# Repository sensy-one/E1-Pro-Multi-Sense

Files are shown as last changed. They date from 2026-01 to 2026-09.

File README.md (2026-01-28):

## 🚀 Sensy-One E1 Pro Multi Sense

The all-in-one open-source sensor designed for Home Assistant, refined through real-world user feedback.

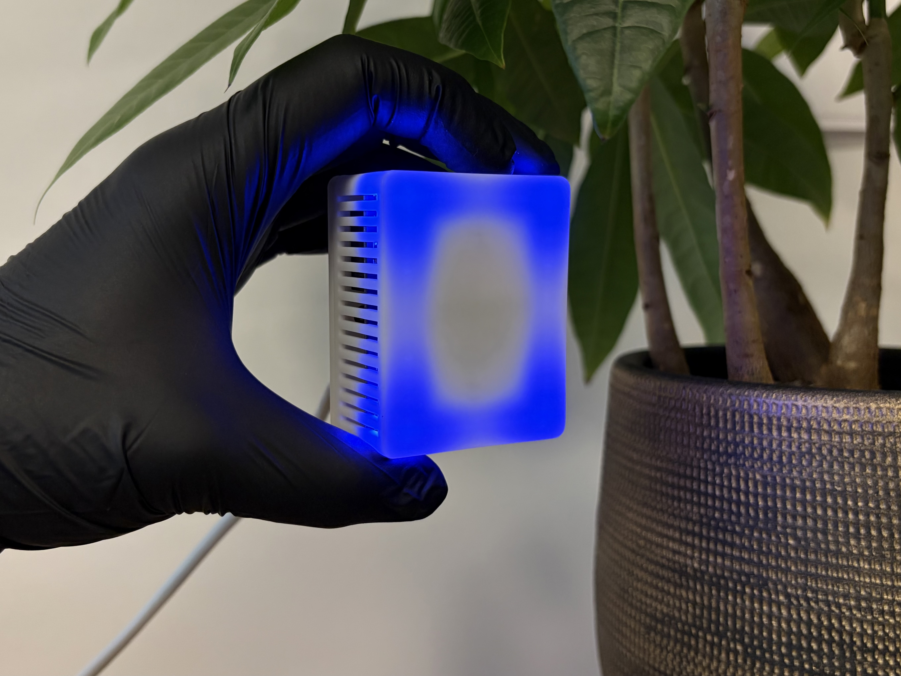
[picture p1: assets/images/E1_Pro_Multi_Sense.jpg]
Sensy-One Banner


The Sensy-One E1 Pro Multi Sense is an open-source presence and environmental sensor, built from the ground up with Home Assistant in mind. After extensive prototyping, firmware tuning, and valuable input from users and smart home enthusiasts, the E1 Pro brings together reliable presence detection, real-time air quality monitoring, and ambient light sensing — all in one compact, Home Assistant-ready device!

## ✨ Standout Specs

**Seamless Home Assistant integration**

The E1 Pro is automatically discovered by Home Assistant when running in PoE (Ethernet) mode.

If you choose the Wi-Fi firmware, the device will be automatically discovered via BLE Improv.  
If BLE discovery is not available or fails, the E1 Pro will start its own wireless access point to complete the setup and connect the sensor to Home Assistant — no additional tools required.

**Powered by ESP32-C3**

At its core, the E1 Pro uses the ESP32-C3 module — offering reliable Wi-Fi, Bluetooth Low Energy, and Ethernet support, low power consumption, and full compatibility with ESPHome and Home Assistant integrations.

**Modular mounting options**

The E1 Pro supports modular built-in mounting options for flexible installation, including flush in-wall and in-ceiling add-ons for a clean, integrated finish.

> Note: These built-in mounting options are currently in development and will be released soon, including STEP and STL files for DIY 3D printing, with the option to purchase the mounting add-ons if you don’t have access to a 3D printer.

**Precision-engineered enclosure**

The custom enclosure is optimized for reliable sensing and long-term operation, featuring minimal mmWave signal interference, optimized airflow across sensors, and a passive cooling design. The resin-printed enclosure ensures a clean, high-quality finish and measures 65 × 52 × 30 mm.

**Advanced mmWave presence sensing**

Built around the Hi-Link LD2460 mmWave presence radar module, the E1 Pro continuously tracks presence in real space, including position, distance, and movement. The system supports tracking of up to five targets simultaneously with fast, stable updates at approximately 30 ms.

Dedicated wall and ceiling detection modes ensure accurate sensing for different mounting positions. With support for three configurable detection zones and one exclusion zone, you can precisely control where presence should trigger automations and where it should be ignored.

The radar supports multiple operating modes:
- Side mode with a detection range of up to 6 m, a 120° horizontal field of view, and a 35° vertical pitch angle
- Top-down mode with full 360° coverage and up to an 8 m diameter

Adjustable sensitivity levels (High, Medium, Low) allow fine-tuning for different environments, delivering reliable and responsive presence detection.

**BLE presence & proximity**

The E1 Pro includes a built-in BLE Proxy for Bluetooth-based presence and proximity detection. The BLE Proxy can be enabled or disabled as needed, allowing seamless integration with Home Assistant and other BLE-based tracking solutions for accurate room-level detection of smartphones, wearables, and tags.

**Full-color status LEDs**

The E1 Pro features four front-facing full-color RGB LEDs, providing clear visual feedback for status indication, presence detection, alerts, and ambient lighting effects.

**Built-in buzzer**

The integrated MLT-8530 buzzer delivers clear audio alerts at 80–90 dB and 2.7 kHz, perfect for notifications, warnings, or presence feedback.

**Comprehensive environmental monitoring**

The E1 Pro is equipped with the Bosch BME280 sensor, providing air pressure measurements for environmental monitoring and system integration.

> Note: Temperature and humidity readings from the BME280 are disabled due to self-heating effects inside the enclosure. Air pressure data is used to support the optional SCD40 add-on, which provides accurate CO₂, temperature, and humidity measurements without self-heating impact.

**High-precision CO₂ sensing (add-on)**

For highly accurate air quality measurements, the E1 Pro supports an optional Sensirion SCD40 add-on module. This add-on provides precise CO₂, temperature, and humidity readings and connects directly to the main PCB via a Molex mezzanine connector — no soldering required.

> Note: An optional Bosch BME688 air quality add-on for the E1 Pro is currently in development and will be released soon. This add-on will enable monitoring of eCO₂, VOCs, IAQ, and gas resistance, providing broader air quality insight similar to the S1 Pro.

**Ambient light and UV sensing**

The integrated Lite-On LTR-390UV sensor measures both illuminance (Lux) and UV index (UVI), enabling smart lighting control and sun exposure awareness based on real-time ambient conditions.

## ⚡ From Power On to Home Assistant

The E1 Pro supports Power over Ethernet (PoE) and is automatically discovered by Home Assistant when connected via Ethernet.

If PoE is not available, the device can be powered using 5V USB-C in combination with an RJ45 Ethernet connection.

When using Wi-Fi mode, the E1 Pro can be powered via USB-C or PoE.  
Wi-Fi setup is handled using Bluetooth (Improv) or the built-in access point.

If your Home Assistant setup supports Bluetooth (Improv):
- The E1 Pro will be automatically discovered under Devices & Services.
- Click Add, enter your Wi-Fi credentials, and you're done.

If Bluetooth is not available:
- The E1 Pro will start a Wi-Fi access point named I am Sensy!.
- Connect to it and open http://192.168.4.1 in your browser.
- Enter your Wi-Fi details, click Save, and it will connect to your network.
- The device will then appear in Home Assistant as a discovered device.

## 📍 Best Placement Practices

**Recommended mounting height**

Wall mounting mode:
- 1.6 to 2.6 meters from the floor

Top-down (ceiling) mounting mode:
- 2.0 to 3.0 meters from the floor

**Placement tips:**
- Ensure a clear line of sight to the monitored area — walls, plants, or furniture can reduce detection accuracy.
- Avoid placing near large metal objects (such as fridges, pipes, or servers), as they can reflect mmWave signals.
- Avoid direct airflow from HVAC vents or fans to maintain stable environmental readings.
- Mount away from heat sources to prevent temperature distortion.

## 🧪 CO₂ Calibration (SCD40 add-on)

For faster or more precise calibration, you can use the Forced Calibration button in Home Assistant.

**To calibrate CO₂ manually:**
- Place the sensor in fresh outdoor air.
- In Home Assistant, click Forced Calibration on the E1 Pro.
- The sensor will set a new baseline of 426 ppm (current global outdoor CO₂ level).

**Temperature offset:**
The SCD40 temperature offset is factory-calibrated based on the enclosure design to compensate for internal heat. This offset can also be manually adjusted in Home Assistant if needed to fine-tune temperature accuracy for your environment.

## 🎯 Get in the Zone

The E1 Pro supports up to 3 detection zones and 1 exclusion zone — all configurable as custom polygons with up to 8 points each.  
Instead of adjusting multiple number entities, zones can be configured visually using the Zone Editor tool.

The Zone Editor is available as an official Home Assistant add-on or Docker image and can be found [here](https://github.com/sensy-one/home-assistant-addons).

## 📶 Flashing Wi-Fi Firmware

To switch the E1 to Wi-Fi mode, you need to flash the Wi-Fi factory firmware manually.

**Flash Wi-Fi factory firmware**
- Download the latest Wi-Fi factory firmware from the [releases page](https://github.com/sensy-one/E1-Pro-Multi-Sense/releases).
- Connect the E1 to your computer using a USB-C cable.
- Open the ESPHome web flasher: https://web.esphome.io/
- Click Connect and select the correct COM port.
- Choose Install and select the Wi-Fi factory firmware file you downloaded.
- Once flashing is complete, disconnect and power the E1 using USB-C or PoE.
- The E1 will start Wi-Fi provisioning using Bluetooth (Improv) or its built-in access point.

## 🔄 Firmware on the Fly

Keep your E1 up to date with regular OTA updates.  
We continuously improve performance and add new features to keep your device reliable and future-ready.

**Install OTA Updates**
- Download the latest OTA firmware from the [releases page](https://github.com/sensy-one/E1-Pro-Multi-Sense/releases).
- In Home Assistant, go to Devices & Services, ESPHome.
- Select your E1 and click Visit under Device Info to open the web interface.
- Scroll down to OTA Update, choose the firmware file, and click Update.

> Tip: If the page times out during upload, simply refresh the page and try again.

## 🛠 Troubleshooting

If your sensor isn’t behaving as expected, reinstalling the factory firmware can help you start fresh.

**Install Factory Firmware**
- Download the latest factory firmware from the [releases page](https://github.com/sensy-one/E1-Pro-Multi-Sense/releases).
- Connect the E1 to your computer using a USB-C cable.
- Open the ESPHome web wizard: https://web.esphome.io/?dashboard_wizard
- Click Connect and select the correct COM port.
- Choose Install, select the firmware file you downloaded, and click Install again.

## 💬 Let’s Connect

Your feedback helps us improve. Whether you’ve found a bug, need help, or want to suggest a feature — we’re listening.

**Discord**
- Join the community and get support on our [Discord server](https://discord.gg/TB78Wprn66).

**GitHub Issues**
- Found a bug or have a suggestion? Report it on our [GitHub issues page](https://github.com/sensy-one/E1-Pro-Multi-Sense/issues).

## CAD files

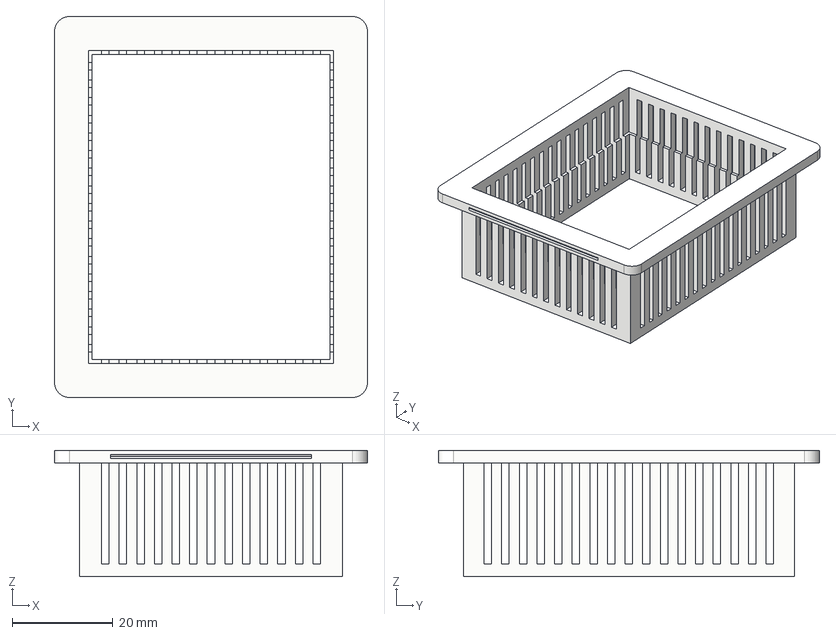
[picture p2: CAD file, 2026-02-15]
assets/step/E1_Pro_Mount_Back.step
62.2 x 75.7 x 25.1 mm

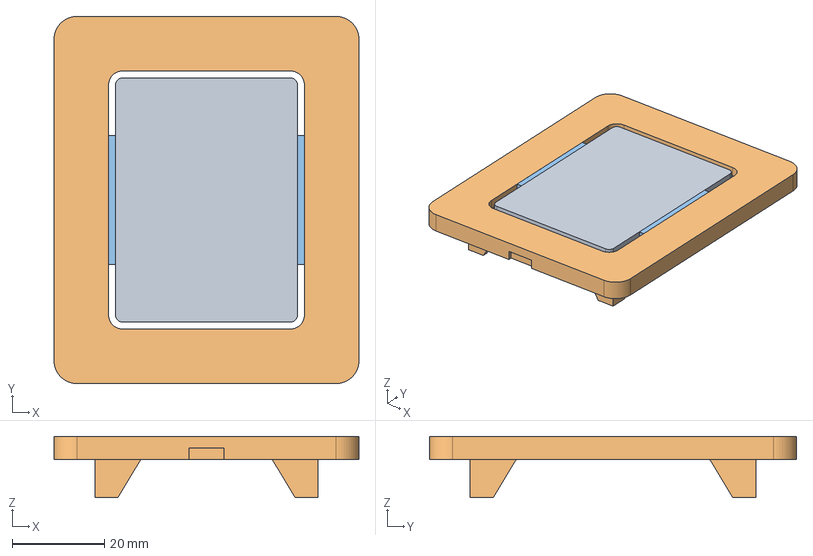
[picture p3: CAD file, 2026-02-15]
assets/step/E1_Pro_Mount_Front.step
66.2 x 79.7 x 13.3 mm

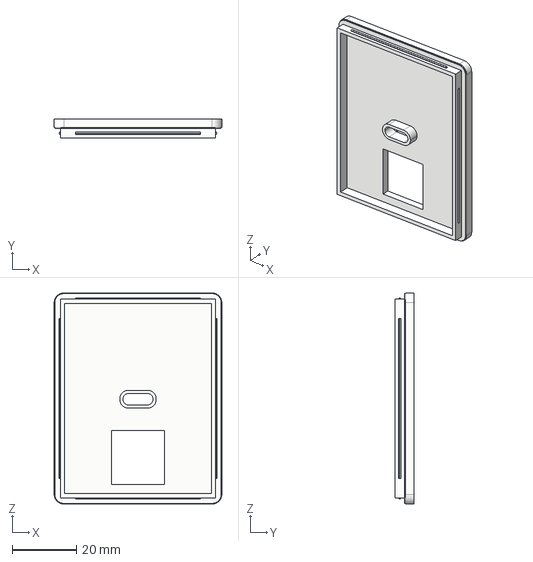
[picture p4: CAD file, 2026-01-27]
assets/step/E1_Pro_Back.step
52.2 x 6.00 x 65.7 mm

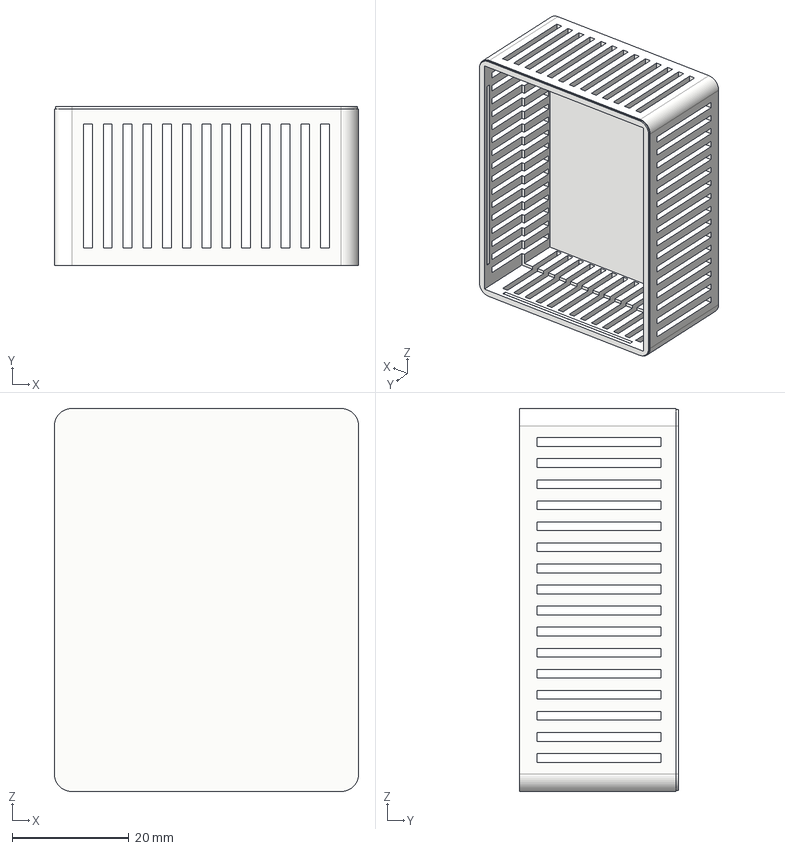
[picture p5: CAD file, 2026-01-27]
assets/step/E1_Pro_Front.step
52.2 x 27.2 x 65.7 mm

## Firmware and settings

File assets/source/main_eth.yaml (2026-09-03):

esphome: 
  name: "e1-pro-multi-sense"
  friendly_name: "E1 Pro Multi Sense"
  name_add_mac_suffix: true
  project:
    name: "Sensy-One.E1 Pro Multi Sense" 
    version: "v1.1.9 (ETH)"  
 
  on_boot: 
    - priority: 600
      then: 
        - if: 
            condition: 
              lambda: 'return !id(onboarding_done);'
            then: 
              - light.turn_on: 
                  id: ws2812_LED
                  effect: "Purple Breathing"
            else: 
              - lambda: '/* NaN */'

    - priority: 750
      then: 
        - if: 
            condition: 
              switch.is_on: ble_proxy_switch
            then: 
              - lambda: |-
                  id(bt_proxy).set_active(true);
              - esp32_ble_tracker.start_scan:
                  id: ble_tracker
            else: 
              - esp32_ble_tracker.stop_scan:
                  id: ble_tracker
              - lambda: |-
                  id(bt_proxy).set_active(false);

    - priority: 800
      then:
        - lambda: |-
            if (!isnan(id(scd40_temp_offset).state)) {
              id(scd40_sensor)->set_temperature_offset((float) id(scd40_temp_offset).state);
            }
        - lambda: |-
            if (!isnan(id(bme688_temp_offset).state)) {
              id(bsec_virtual_sensor)->set_temperature_offset((float) id(bme688_temp_offset).state);
            }

    - priority: 900
      then:
        - delay: 5s
        - lambda: |-
            id(e1_sensor).query_all_settings();

script:
  - id: finish_onboarding
    mode: restart
    then:
      - light.turn_on:
          id: ws2812_LED
          red: 100%
          green: 0%
          blue: 30% 
          brightness: 100%
      - delay: 2s
      - light.turn_off: ws2812_LED
      - lambda: 'id(onboarding_done) = true;'

# external_components:
#   - source:
#       type: local
#       path: components

external_components:
  - source:
      type: git
      url: https://github.com/sensy-one/E1-Pro-Multi-Sense
      ref: main
      path: assets/source/components
    components: [e1_pro]

dashboard_import:
  package_import_url: github://sensy-one/E1-Pro-Multi-Sense/assets/source/main_eth.yaml@main
  import_full_config: true

# dashboard_import:
#   package_import_url: github://sensy-one/E1-Pro-Multi-Sense/assets/source/main_wifi.yaml@main
#   import_full_config: true

esp32:
  board: esp32-c3-devkitm-1
  framework:
    type: esp-idf
    sdkconfig_options:
      CONFIG_BOOTLOADER_APP_ROLLBACK_ENABLE: n

ethernet:
  type: W5500
  mosi_pin: GPIO1
  miso_pin: GPIO10
  clk_pin: GPIO4
  cs_pin: GPIO8
  reset_pin: GPIO2
  interrupt_pin: GPIO3
  clock_speed: 10MHz

# esp32_improv:
#    authorizer: none

# wifi:
#   ap:
#     ssid: "I am Sensy!"
#     ap_timeout: 1min

# captive_portal: 

# improv_serial:

esp32_ble_tracker:
  id: ble_tracker
  scan_parameters:
    interval: 320ms
    window: 300ms
    active: true

bluetooth_proxy:
  id: bt_proxy
  active: false

logger:
  level: NONE
  baud_rate: 115200

api:
  reboot_timeout: 0s
  on_client_connected:
    then:
      - if:
          condition:
            lambda: 'return !id(onboarding_done);'
          then:
            - script.execute: finish_onboarding
          else:
            - lambda: '/* NaN */'

ota:
  - platform: esphome
  - platform: web_server
  - platform: http_request

http_request:
  timeout: 30s
  watchdog_timeout: 60s
  buffer_size_rx: 4096
  buffer_size_tx: 1024

update:
  - platform: http_request
    id: firmware_update
    name: "ESP32 | Firmware Update"
    source: https://github.com/sensy-one/E1-Pro-Multi-Sense/releases/latest/download/manifest_eth.json
    update_interval: 6h

  # - platform: http_request
  #   id: firmware_update
  #   name: "ESP32 | Firmware Update"
  #   source: https://github.com/sensy-one/E1-Pro-Multi-Sense/releases/latest/download/manifest_wifi.json
  #   update_interval: 6h

web_server:
  version: 3

uart:
  id: uart_bus
  tx_pin: GPIO21
  rx_pin: GPIO20
  baud_rate: 115200
  rx_buffer_size: 4096 

i2c:
  id: i2c_bus
  sda: GPIO5
  scl: GPIO6
  scan: false

output:
  - platform: ledc
    id: mlt8530_buzzer
    pin: GPIO7
    frequency: 2700 Hz
    inverted: false

bme68x_bsec2_i2c:
  i2c_id: i2c_bus
  id: bsec_virtual_sensor
  address: 0x77
  model: bme688
  sample_rate: LP
  supply_voltage: 3.3V
  state_save_interval: 6h
  operating_age: 4d

globals:
  - id: onboarding_done
    type: bool
    restore_value: true
    initial_value: 'false'

  - id: env_publish_live
    type: bool
    restore_value: true
    initial_value: 'true'
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

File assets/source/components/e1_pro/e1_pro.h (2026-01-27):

#pragma once

#include "esphome.h"
#include "esphome/components/uart/uart.h"
#include "esphome/components/number/number.h"
#include "esphome/components/select/select.h"
#include <cmath>
#include <vector>

namespace esphome {
namespace e1_pro {

class LD2460 : public Component, public uart::UARTDevice {
 public:
  LD2460();

  void set_exclusion_zone_points_count(number::Number *count) { exclusion_zone_points_count = count; }
  void set_exclusion_zone_p1_x(number::Number *p) { exclusion_zone_points[0][0] = p; }
  void set_exclusion_zone_p1_y(number::Number *p) { exclusion_zone_points[0][1] = p; }
  void set_exclusion_zone_p2_x(number::Number *p) { exclusion_zone_points[1][0] = p; }
  void set_exclusion_zone_p2_y(number::Number *p) { exclusion_zone_points[1][1] = p; }
  void set_exclusion_zone_p3_x(number::Number *p) { exclusion_zone_points[2][0] = p; }
  void set_exclusion_zone_p3_y(number::Number *p) { exclusion_zone_points[2][1] = p; }
  void set_exclusion_zone_p4_x(number::Number *p) { exclusion_zone_points[3][0] = p; }
  void set_exclusion_zone_p4_y(number::Number *p) { exclusion_zone_points[3][1] = p; }
  void set_exclusion_zone_p5_x(number::Number *p) { exclusion_zone_points[4][0] = p; }
  void set_exclusion_zone_p5_y(number::Number *p) { exclusion_zone_points[4][1] = p; }
  void set_exclusion_zone_p6_x(number::Number *p) { exclusion_zone_points[5][0] = p; }
  void set_exclusion_zone_p6_y(number::Number *p) { exclusion_zone_points[5][1] = p; }
  void set_exclusion_zone_p7_x(number::Number *p) { exclusion_zone_points[6][0] = p; }
  void set_exclusion_zone_p7_y(number::Number *p) { exclusion_zone_points[6][1] = p; }
  void set_exclusion_zone_p8_x(number::Number *p) { exclusion_zone_points[7][0] = p; }
  void set_exclusion_zone_p8_y(number::Number *p) { exclusion_zone_points[7][1] = p; }

  void set_installation_method_select(select::Select *s) { install_mode_select_ = s; }
  void set_installation_angle_select(select::Select *s) { install_angle_select_ = s; }
  void set_installation_height_select(select::Select *s) { install_height_select_ = s; }
  void set_sensitivity_select(select::Select *s) { sensitivity_select_ = s; }
  void set_side_range_select(number::Number *s) { side_range_select_ = s; }
  void set_top_range_select(number::Number *s) { top_range_select_ = s; }

  void send_restart();
  void send_factory_reset();
  void send_set_installation_mode(bool top);
  void send_set_installation_params(float height_m, float angle_deg);
  void send_set_detection_range(float distance_m, float angle_start_deg, float angle_end_deg);
  void send_set_sensitivity(uint8_t value);

  void send_query_installation_mode();
  void send_query_installation_params();
  void send_query_detection_range();
  void send_query_sensitivity();
  void query_all_settings();

  void setup() override;
  void loop() override;

 protected:
  void parse_frame(const uint8_t *b, uint16_t len);
  void parse_command_frame_(const uint8_t *b, uint16_t len);
  void send_frame_(uint8_t function, const std::vector<uint8_t> &data_content);
  bool is_in_exclusion_zone(float x, float y);

  struct Track {
    float  x{0}, y{0}, angle{0}, dist{0};
  } tracks_[5];

  void publish_zero_(int t);
  void publish_track_(int t, const Track &tr);
  void update_track_(int t, bool meas_valid,
                     float x, float y, float angle, float dist);

 public:
  sensor::Sensor *target1_x, *target1_y, *target1_angle, *target1_distance;
  sensor::Sensor *target2_x, *target2_y, *target2_angle, *target2_distance;
  sensor::Sensor *target3_x, *target3_y, *target3_angle, *target3_distance;
  sensor::Sensor *target4_x, *target4_y, *target4_angle, *target4_distance;
  sensor::Sensor *target5_x, *target5_y, *target5_angle, *target5_distance;

  number::Number *exclusion_zone_points_count{nullptr};
  number::Number *exclusion_zone_points[8][2]{};

  select::Select *install_mode_select_{nullptr};
  select::Select *install_angle_select_{nullptr};
  select::Select *install_height_select_{nullptr};
  select::Select *sensitivity_select_{nullptr};
  number::Number *side_range_select_{nullptr};
  number::Number *top_range_select_{nullptr};

  static constexpr int kMaxFrame = 96;
  uint8_t rx_buf_[kMaxFrame]{};
  int header_pos_{0};
  int idx_{0};
  uint16_t expected_len_{0};
  uint8_t func_{0};
  bool target_frame_{false};
  enum class RxState { SYNC, READ_HEADER, READ_FUNC, READ_LEN1, READ_LEN2, READ_REST };
  RxState rx_state_{RxState::SYNC};
  uint8_t current_mode_{0x00};
  float pending_range_cm_{0.0f};
  bool pending_range_valid_{false};
  float pending_height_m_{0.0f};
  float pending_angle_deg_{0.0f};
  bool pending_params_valid_{false};
  uint32_t query_generation_{0};
};

inline LD2460::LD2460() : Component(), uart::UARTDevice() {
  target1_x        = new sensor::Sensor(); target1_y        = new sensor::Sensor();
  target1_angle    = new sensor::Sensor(); target1_distance = new sensor::Sensor();
  target2_x        = new sensor::Sensor(); target2_y        = new sensor::Sensor();
  target2_angle    = new sensor::Sensor(); target2_distance = new sensor::Sensor();
  target3_x        = new sensor::Sensor(); target3_y        = new sensor::Sensor();
  target3_angle    = new sensor::Sensor(); target3_distance = new sensor::Sensor();
  target4_x        = new sensor::Sensor(); target4_y        = new sensor::Sensor();
  target4_angle    = new sensor::Sensor(); target4_distance = new sensor::Sensor();
  target5_x        = new sensor::Sensor(); target5_y        = new sensor::Sensor();
  target5_angle    = new sensor::Sensor(); target5_distance = new sensor::Sensor();
}

inline void LD2460::send_frame_(uint8_t function, const std::vector<uint8_t> &data_content) {
  const uint8_t header[4] = {0xFD, 0xFC, 0xFB, 0xFA};
  const uint8_t footer[4] = {0x04, 0x03, 0x02, 0x01};
  std::vector<uint8_t> frame;
  uint16_t total_len = 4 + 1 + 2 + data_content.size() + 4;
  frame.reserve(total_len);
  frame.insert(frame.end(), header, header + 4);
  frame.push_back(function);
  frame.push_back(total_len & 0xFF);
  frame.push_back((total_len >> 8) & 0xFF);
  frame.insert(frame.end(), data_content.begin(), data_content.end());
  frame.insert(frame.end(), footer, footer + 4);
  this->write_array(frame.data(), frame.size());
}

inline void LD2460::send_restart() { send_frame_(0x0D, {0x01}); }
inline void LD2460::send_factory_reset() { send_frame_(0x10, {0x01}); }

inline void LD2460::send_set_installation_mode(bool top) {
  uint8_t mode = static_cast<uint8_t>(top ? 0x02 : 0x01);
  send_frame_(0x09, {mode});
}

inline void LD2460::send_set_installation_params(float height_m, float angle_deg) {
  uint16_t height_val = static_cast<uint16_t>(std::round(height_m * 100.0f));
  uint16_t angle_val = static_cast<uint16_t>(std::round(angle_deg * 100.0f));
  send_frame_(0x07, {
    (uint8_t)(height_val & 0xFF), (uint8_t)(height_val >> 8),
    (uint8_t)(angle_val & 0xFF), (uint8_t)(angle_val >> 8)
  });
}
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

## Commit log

2026-02-15 Add build-in mount .step files
    [E1_Pro_Mount_Back.step, E1_Pro_Mount_Front.step]
2026-03-12 Add switch to toggle live vs 60s sensor updates
2026-03-16 Add BME688 BSEC2 sensor add-on integration
2026-04-05 Fix prevent HA clamping zones outside FOV
    [main_eth.yaml, main_wifi.yaml]
2026-06-04 Enable ESP32 Improv
2026-09-03 Fix template select compatibility with ESPHome 2026.7
    [main_eth.yaml, main_wifi.yaml]
2026-11-04 Add .stl files: round ceiling built-in mount
